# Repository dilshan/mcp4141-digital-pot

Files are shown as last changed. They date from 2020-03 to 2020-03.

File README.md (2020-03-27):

# MCP4141 based digital potentiometer

> MCP4141 and ATtiny13 based digital potentiometer to replace an
> existing 3 terminal analog potentiometers.

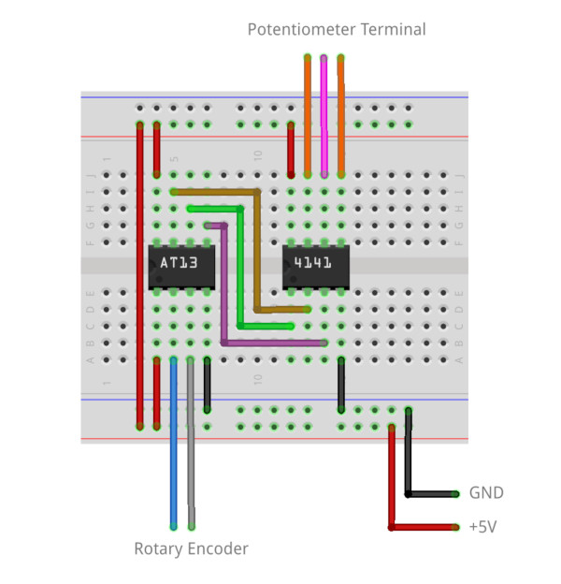
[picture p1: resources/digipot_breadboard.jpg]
Breadboard View


The main objective of this project is to create a prototype version of a digital potentiometer using *Microchip*'s MCP4141 IC. MCP4141 is available with end-to-end resistances of 5KΩ, 10KΩ, 50kΩ, and 100KΩ. This potentiometer-module can drive MCP4141 with any of the above mention resistances.

To drive the MCP4141, this module use ATtiny13 MCU. This MCU control MCP4141's resistance, based on the rotary-encoder events. ATtiny13 is an 8-pin, low power 8-bit MCU with an internal oscillator. The key reason to pick this MCU is its availability and lower price. Due to a lack of hardware-based SPI, this system use bit-banging SPI implementation to drive the MCP4141 IC. 

Schematic

To reduce the board size, this module employs only 3 components. Which including ATtiny13, MCP4141, and rotary-encoder. The dimension of the PCB design given for this module is 26.16mm x 29.72mm. 

## Building and flash firmware

Firmware of this module is developed using AVR-GCC toolchain. To build the firmware execute the `make` command.

To flash the compiled firmware, use the following set of commands:

    make fuse
    make flash

The `make fuse` command can use to set up the fuse-bits of the MCU and it needs to execute only once.

## License

This is an open-source hardware project. Compiled firmware, PCB designs, schematic, and source codes related to this project are available at this repository. 

The firmware of this project is licensed under the terms of [MIT license](https://github.com/dilshan/mcp4141-digital-pot/blob/master/LICENSE). Hardware design and related content are licensed under [Creative Commons - Attribution 4.0 International](https://creativecommons.org/licenses/by/4.0/) ([CC BY 4.0](https://creativecommons.org/licenses/by/4.0/)) license.

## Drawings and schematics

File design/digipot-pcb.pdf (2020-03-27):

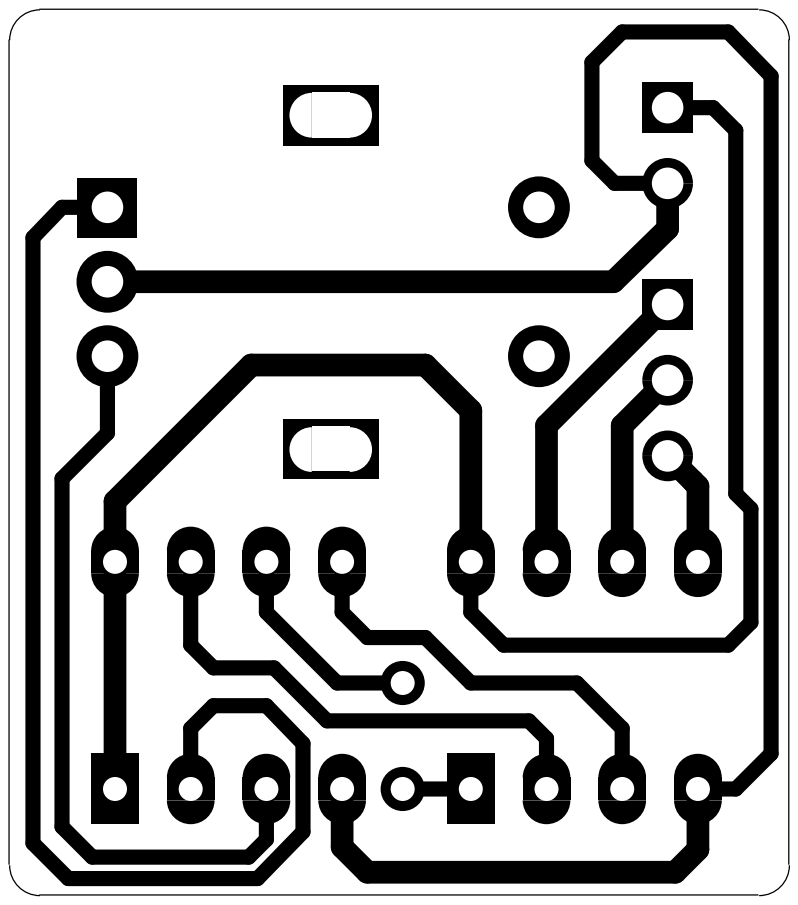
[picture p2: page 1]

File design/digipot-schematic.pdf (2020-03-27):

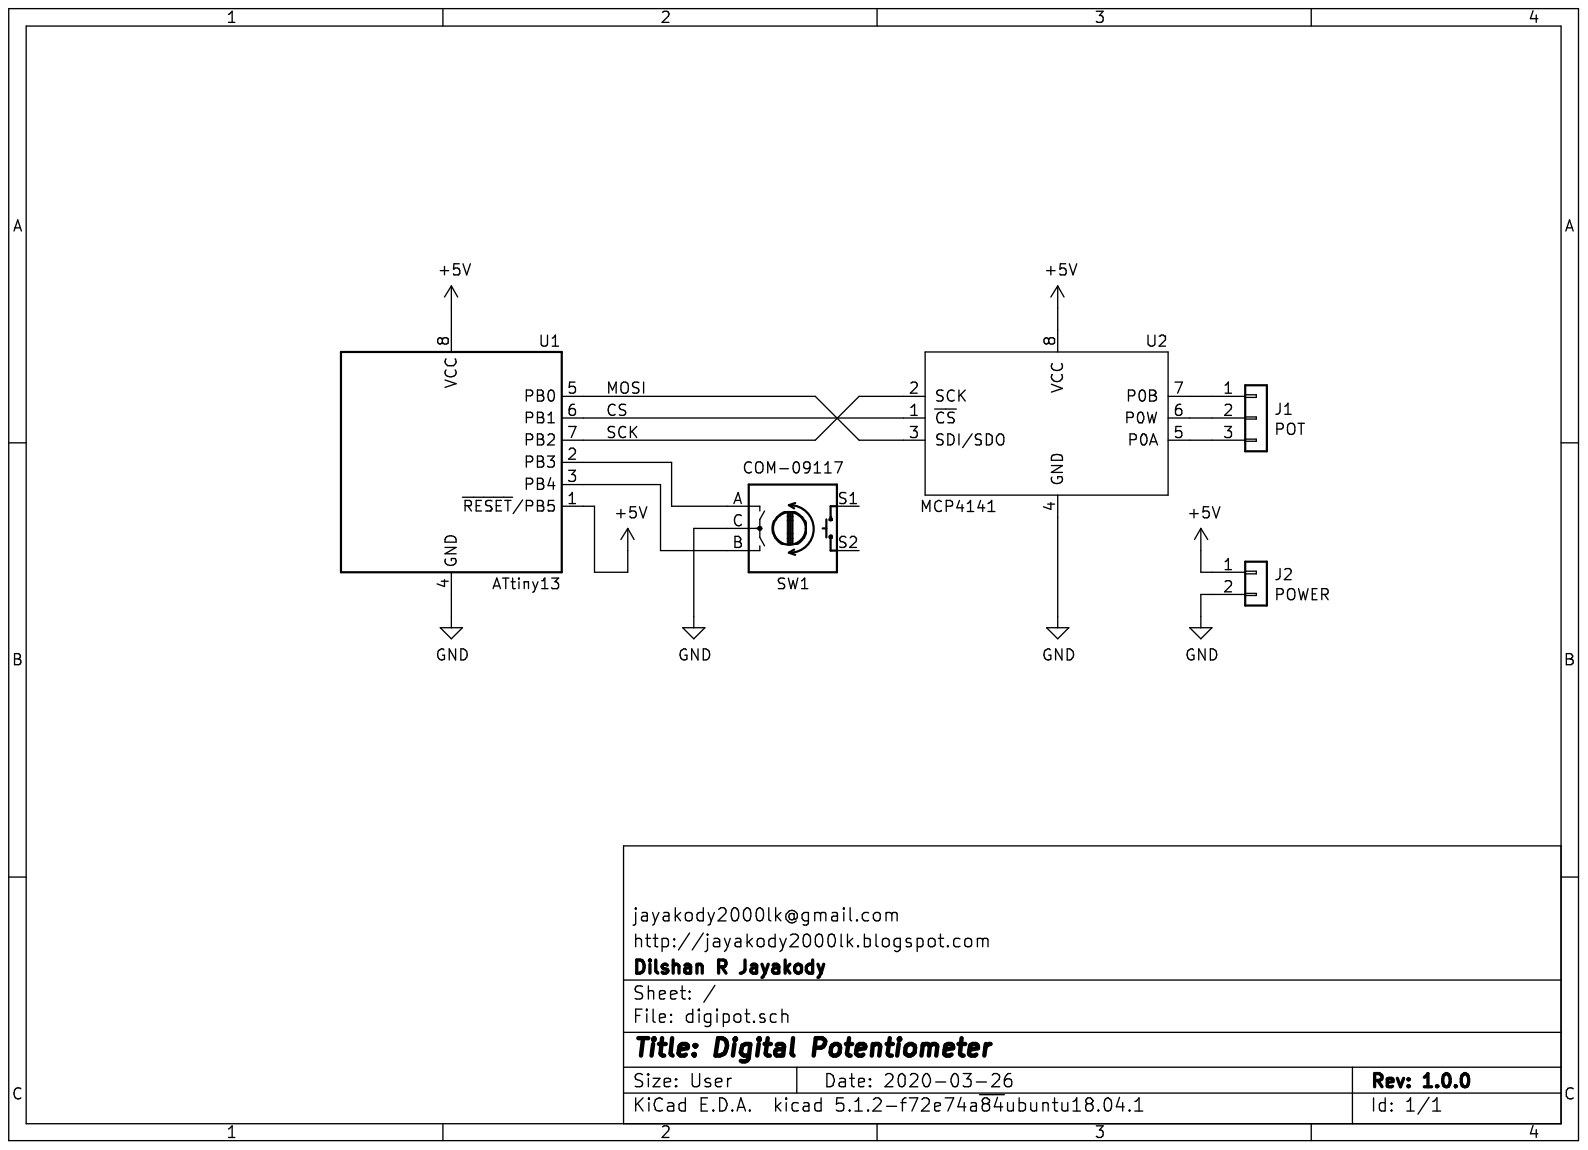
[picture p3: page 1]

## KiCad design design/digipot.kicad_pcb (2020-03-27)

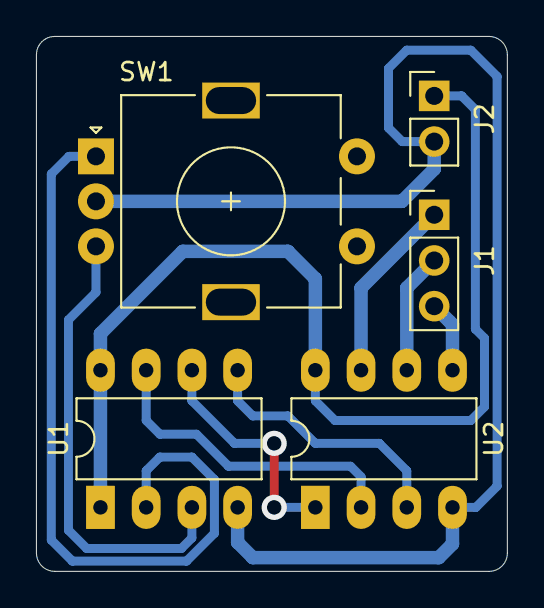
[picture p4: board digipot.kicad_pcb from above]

Board: 2 copper layers, 26.2 x 29.7 mm, 5 parts (0 on the bottom side), 10 nets.

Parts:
J1: POT; PinHeader_1x03_P2.54mm_Vertical
J2: POWER; PinHeader_1x02_P2.54mm_Vertical
SW1: COM-09117; RotaryEncoder_Alps_EC11E-Switch_Vertical_H20mm
U1: ATtiny13; DIP-8_W7.62mm_LongPads
U2: MCP4141; DIP-8_W7.62mm_LongPads

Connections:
+5V: J2.1, U1.1, U1.8, U2.8
/CS: U1.6, U2.1
/MOSI: U1.5, U2.3
/SCK: U1.7, U2.2
GND: J2.2, SW1.C, U1.4, U2.4
unnamed: J1.1, U2.7
unnamed: J1.2, U2.6
unnamed: J1.3, U2.5
unnamed: SW1.A, U1.2
unnamed: SW1.B, U1.3

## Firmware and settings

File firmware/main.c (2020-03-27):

// -------------------------------------------------------------------------------
// MIT License
//
// Copyright (c) 2020 Dilshan R Jayakody
//
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
#include <avr/io.h>
#include <util/delay.h>

#include "main.h"

// ---------------------------------------------------
// - ATTiny 13 Pin     | Connection                  -
// ---------------------------------------------------
// - Pin 1 (RESET)     | +5V (VCC)                   -
// - Pin 2 (IN)        | Rotary Encorder Terminal A  -
// - Pin 3 (IN)        | Rotary Encorder Terminal B  -
// - Pin 4 (GND)       | GND                         -
// - Pin 5 (MOSI)      | MCP4141 SDI/SDO             -
// - Pin 6 (CS)        | MCP4141 CS                  -
// - Pin 7 (SCK)       | MCP4141 SCK                 -
// - Pin 8 (VCC)       | +5V (VCC)                   -
// ---------------------------------------------------

int main()
{
    // Initialize MCU ports and associated registers.
    DDRB = 0x07;
    PORTB = 0xFF;
    
    unsigned char state, lastState;
    unsigned char secState, potLevel;

    // Load last potentiometer position from EEPROM. 
    _delay_ms(5);
    potLevel = loadPotValue();
    updatePot(potLevel);
    _delay_ms(10);
    updatePot(potLevel);

    // Get status of the rotary encorder.
    lastState = (PINB & 0x08) ? 1 : 0;
    state = lastState;

    while(1)
    {
        state = (PINB & 0x08) ? 1 : 0;        

        // Check for rotary encorder events.
        if(lastState != state)
        {
            secState = (PINB & 0x10) ? 1 : 0;
            if(secState != state)
            {
                // Rotary encorder is in increment direction.
                if(potLevel < 127)
                {
                    potLevel++;
                }
            }
            else 
            {
                // Rotary encorder is in decrement direction.
                if(potLevel > 0)
                {
                    potLevel--;
                }
            }

            // Update potentiometer with new value and save it in EEPROM.
            updatePot(potLevel);
            savePotValue(potLevel);
        }

        lastState = state;
    }
    
    return 0;
}

void updatePot(unsigned char value)
{
    unsigned char pos;

    // Select MCP4141 chip and set MOSI to high.
    PORTB = PORTB | 0x01;
    _delay_us(1);
    PORTB = PORTB & 0xFD;
    _delay_us(1);

    PORTB = PORTB & 0xFE;

    // Send address value as 0x00.
    for (pos = 0x80; pos; pos >>= 1)
    {
        _delay_us(1);
        PORTB = PORTB | 0x04;
        _delay_us(1);
        PORTB = PORTB & 0xFB;
    }

    PORTB = PORTB | 0x01;
    _delay_us(5);

    // Send potentiometer position data.
    for (pos = 0x80; pos; pos >>= 1)
    {
        if(value & pos)
        {
            PORTB = PORTB | 0x01;
        }
        else
        {
            PORTB = PORTB & 0xFE;
        }

        _delay_us(1);
        PORTB = PORTB | 0x04;
        _delay_us(1);
        PORTB = PORTB & 0xFB;
    }

    // Deselect MCP4141 chip and reset MOSI.
    PORTB = PORTB | 0x01;
    _delay_us(5);
    PORTB = PORTB | 0x02;
}

void savePotValue(unsigned char potVal)
{
    // Waiting for last EEPROM update.
    while(EECR & (1<<EEPE));

    // Save specified potentiometer position into address 0x00.
    EECR = (0<<EEPM1)|(0>>EEPM0);
    EEARL = 0x00;
    EEDR = potVal;

    EECR |= (1<<EEMPE);
    EECR |= (1<<EEPE);
}

unsigned char loadPotValue()
{
    unsigned char eepromVal;
    
    while(EECR & (1<<EEPE));

    // Try to load potentiometer position from address 0x00.
    EEARL = 0x00;
    EECR |= (1<<EERE);

    // Trim received value to avoid overflows.
    eepromVal = EEDR;
    return ((eepromVal > 127) ? 0 : eepromVal);
}

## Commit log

2020-03-27 Initial version of firmware and design files.
    [digipot.kicad_pcb, digipot.sch]
2020-03-27 Add schematic and breadboard views. :art:
